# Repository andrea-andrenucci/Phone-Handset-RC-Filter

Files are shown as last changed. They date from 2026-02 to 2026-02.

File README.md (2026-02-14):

# Phone Handset RC Filter
Phones Photo
*I apologise profusely for the inability to make a simple, simmetric photo*
<br></br>

This project is mainly inspired by the works of [Ryan Mobitz](https://www.production-expert.com/production-expert-1/use-an-old-phone-handset-to-produce-a-lo-fi-mic) and [Noisegate](https://noisegate.com.au/how-to-create-a-stereo-microphone-from-an-old-telephone-handset/).

The main contribution of this project is treating the telephone handset as a separate module from the main circuit, which is designed as an independent audio effect stage.

Another major difference is the use of an external power supply. This allows the use of a carbon microphone even without a mixer providing phantom power.  
Thanks to the lower supply voltage (9V instead of the standard 48V phantom power), there is no need for an impedance-matching transformer, significantly reducing manufacturing costs and complexity.

``` Python
The project contains:
    ./imgs/ # All the figures used in the README
    ./schema_and_pcb/ #This contains the main source files
        |
        |-> ./out/ #Files for JLC PCB
        |
        |-> ... # All the kicad files
        |
        |-> ./Case.zip/ #Contains al the .stl for the enclosure
```
More technical info and measurements about the microphone can be found in [MEASUREMENTS](./MEASUREMENTS.md)

## Overview

The circuit is a simple RC-based filter and conditioning stage designed to work with vintage telephone handsets, supporting both the dynamic capsule and the carbon microphone.

The reference in the schematic is an headset from an italian Siemens S62 (aka Bigrigio):

- **Dynamic capsule (≈55 Ω)**
- **Carbon microphone (≈100 kΩ)**

A switch allows selecting the appropriate signal path depending on the capsule type.

The output is provided via a standard **XLR3 panel connector**, making the device compatible with mixers, audio interfaces, and recording systems.

Power is supplied externally through a **9V DC input (center negative)**, the standard de facto for effects.

---

## Electrical Schematic
<center>
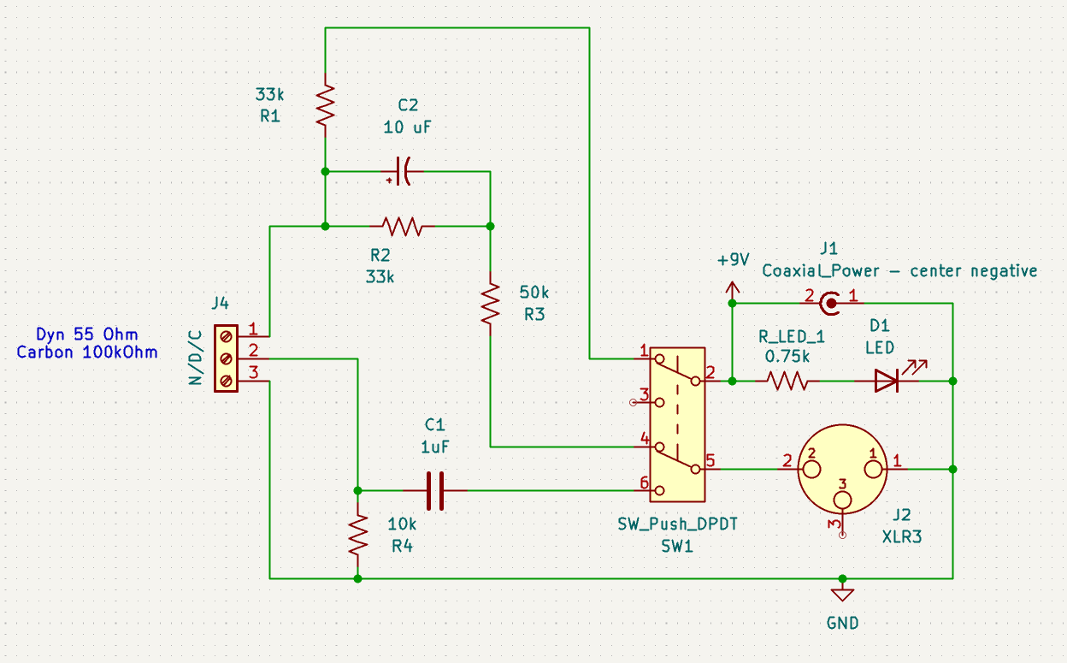
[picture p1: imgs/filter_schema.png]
Filter Schema
    
</center>
<br></br>

Both the schematic and the PCB were designed using **KiCad**.

The circuit can be divided into four main sections:

### 1. Input Section (Handset Connector)
The handset is connected via a 3-pin terminal block:

- Pin 1: Carbon Microphone
- Pin 2: Dynamic Capsule
- Pin 3: Common Ground

<center>
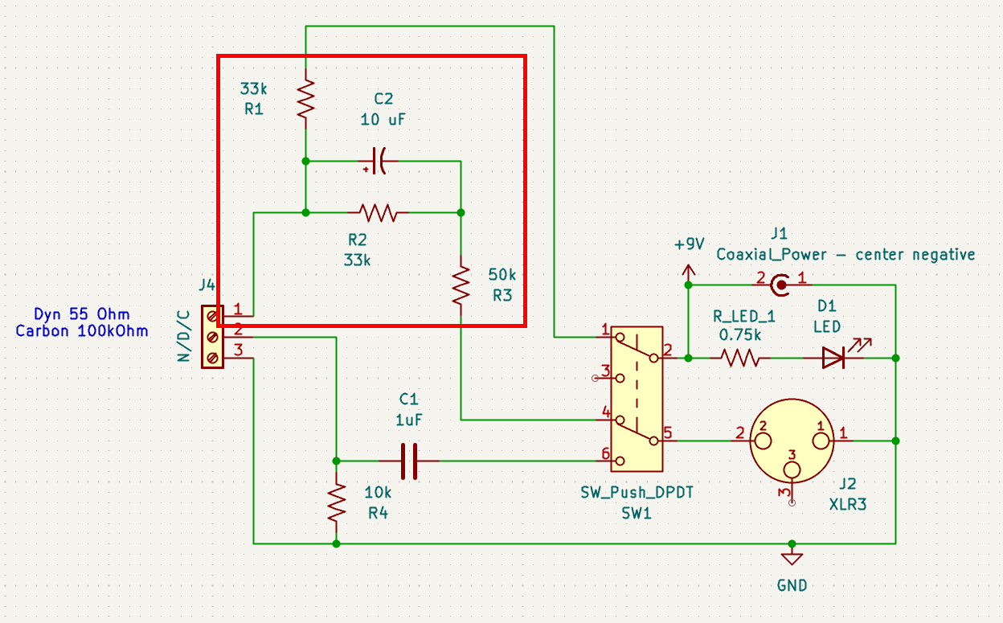
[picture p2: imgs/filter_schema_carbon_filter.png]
Filter Carbon
    
</center>

<br></br>

#### Dynamic Capsule Characteristics

- Very low impedance (~55 Ω)
- Does **not** require bias voltage
- Generates signal directly from diaphragm movement

#### Carbon Microphone Characteristics

- High impedance (~100 kΩ)
- Requires **DC bias current**
- Output is a resistance variation modulating the bias voltage
- Produces strong midrange distortion (classic telephone sound)

Because the two technologies behave completely differently, they require different conditioning paths.

### 2. RC Filter Network
The **R1 (33kΩ)** provides **bias current limiting** for the carbon microphone when in carbon mode. R1:
- Limits current from the 9V supply
- Sets operating point of the carbon capsule
- Prevents excessive noise and overheating

Typical carbon microphones work best with a few milliamps of current.  
33kΩ at 9V provides a safe, low-current bias suitable for vintage elements.

The pair **R2 (33kΩ), C2(10µF)** forms a **high-pass RC filter**.

This network shapes the frequency response, emphasizing the lo-fi telephone character by limiting bandwidth and controlling gain.
The **R3 (50kΩ on the schematic, a 47kΩ was actually used)** resistor acts as a level control.

<center>
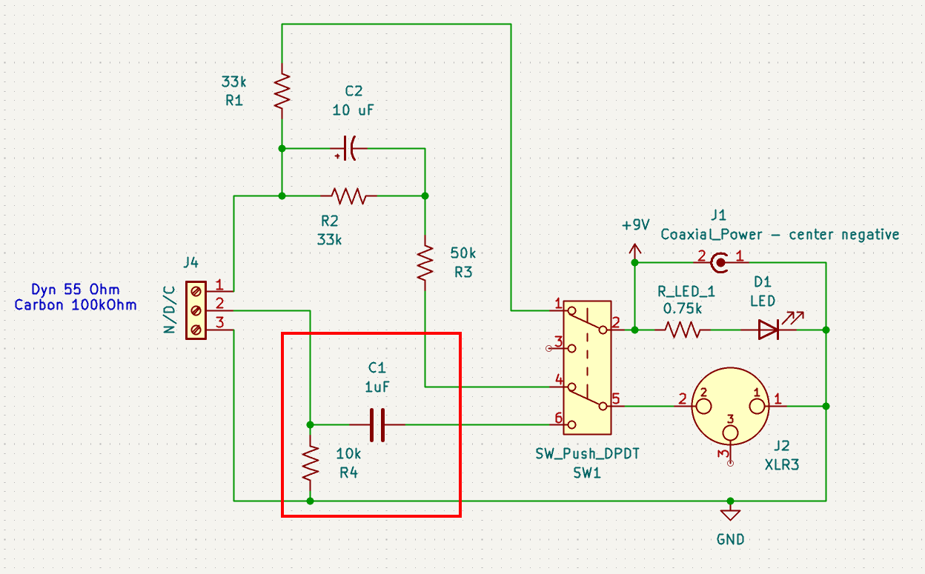
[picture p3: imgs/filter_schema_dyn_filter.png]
Filter Dynamic
    
</center>
<br></br>

**R4 (10kΩ) and C1 (1µF)** work in a similiar fashon, acting as a filter for the dynamic capsule.

This contributes slightly to the “telephone effect”, although the main bandwidth limitation comes from the capsule itself.

### 3. Power and Output Stage

- **9V DC input (center negative)**
- **LED + 750Ω resistor** for power indication
- **XLR3 output connector**

The XLR pinout follows the standard convention:

- Pin 1: Signal -
- Pin 2: Signal +

A **DPDT push switch** allows selecting the correct configuration depending on the capsule type:

- Dynamic mode
- Carbon mode (powered)

This isolates the microphone from the power section when not needed.

<center>
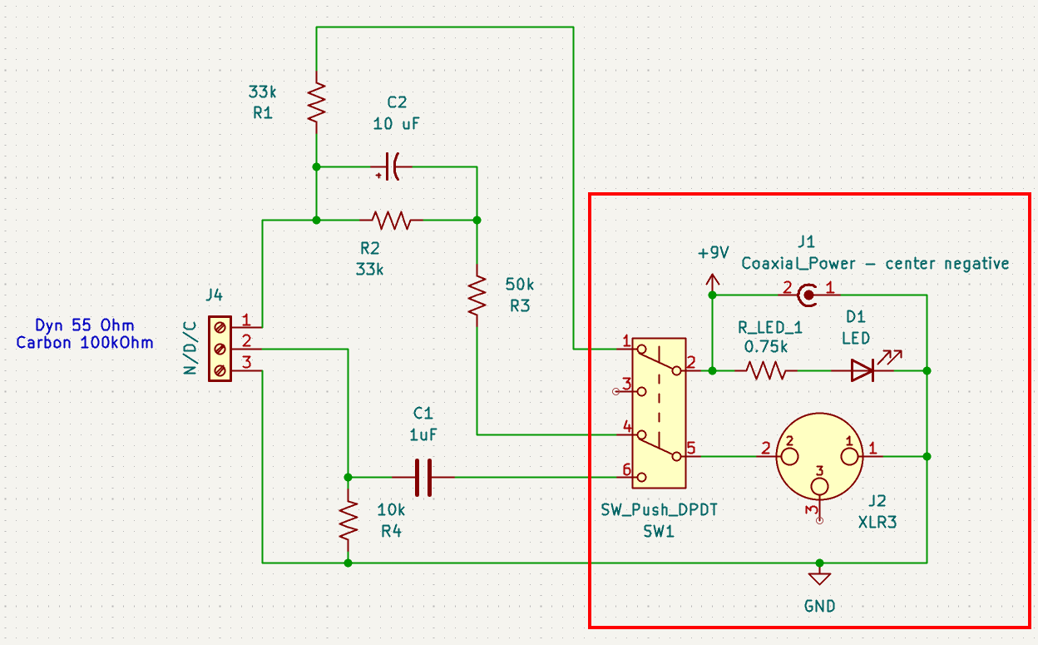
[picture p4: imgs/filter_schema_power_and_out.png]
Filter Power And Output
    
</center>
<br></br>

> Note:  
> This is **not a fully balanced active output**.  
> It is pseudo-balanced/passive and works well for short cable runs.
>
> For professional long runs, an active balanced driver could be added.

---

## PCB

Breadboard

The PCB was designed in KiCad with through-hole components for easy assembly and repair.

Design goals:

- Compact footprint
- Simple routing
- Clear separation between power and signal paths
- Easy integration into a custom enclosure

In order to connect both the DPDT and the XLR i used a **JST** standard 2mm terminal

<center>
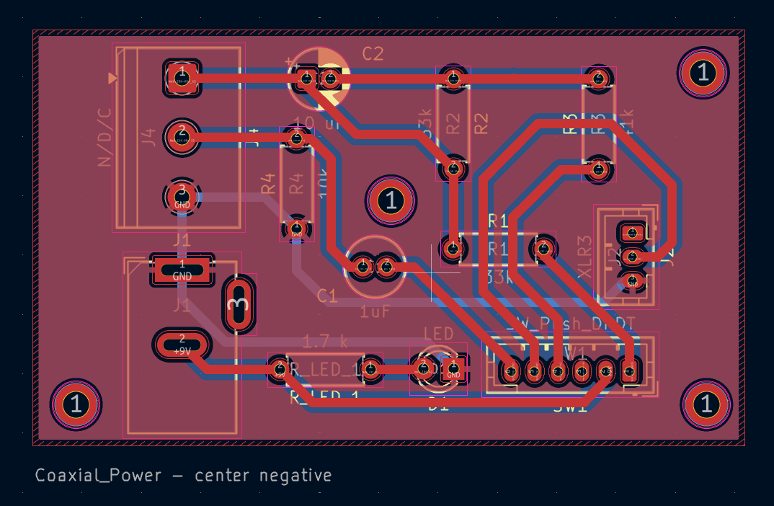
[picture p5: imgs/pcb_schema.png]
PCB Schema
    
</center>

---

## Enclosure

The enclosure was designed in CAD (Onshape) and consists of:

- Base plate
- Main body
- Top plate

The layout ensures mechanical stability and easy access to all connectors.

<center>
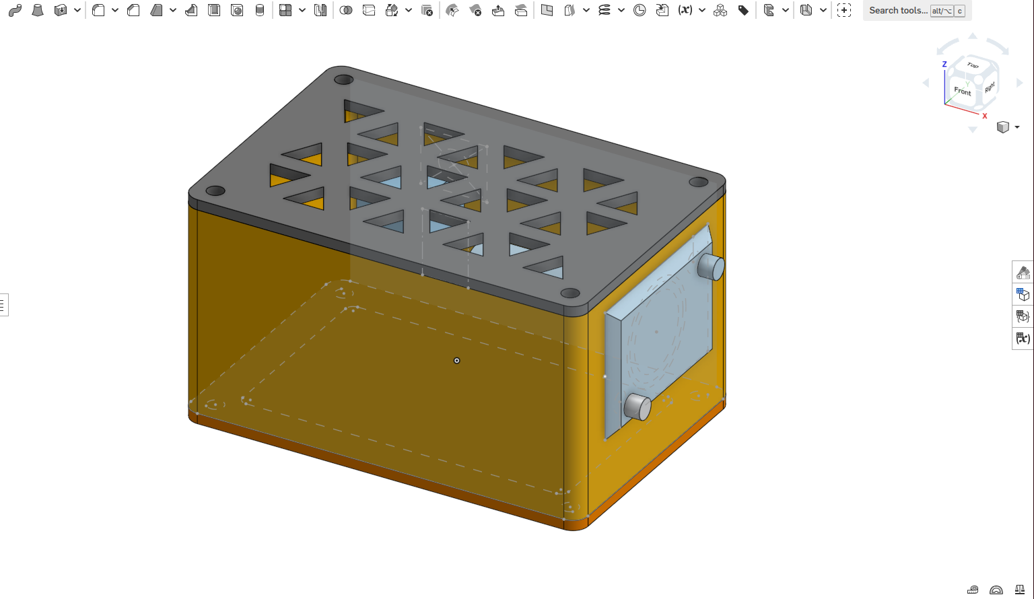
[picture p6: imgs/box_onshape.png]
Box
    
</center>

<center>
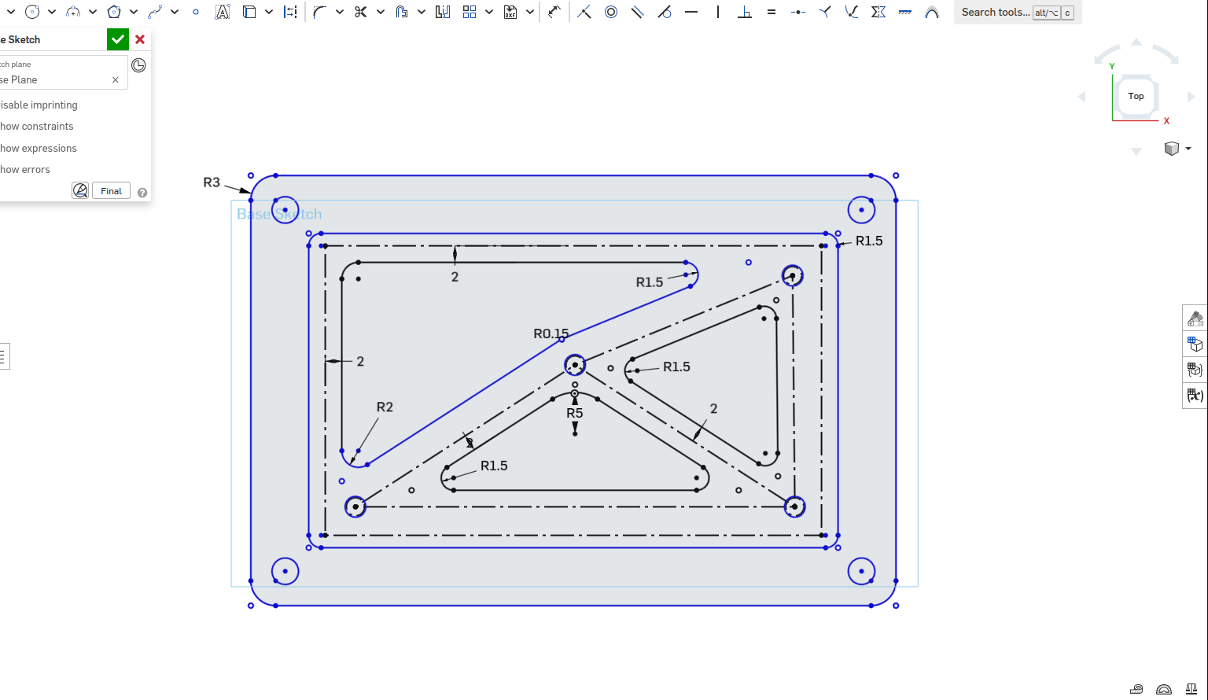
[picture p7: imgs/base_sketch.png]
Box Base
    
</center>

<center>
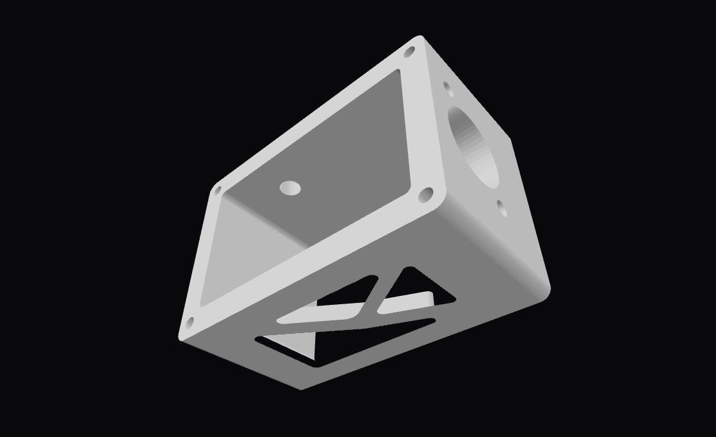
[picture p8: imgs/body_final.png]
Final Body
    
</center>

<center>
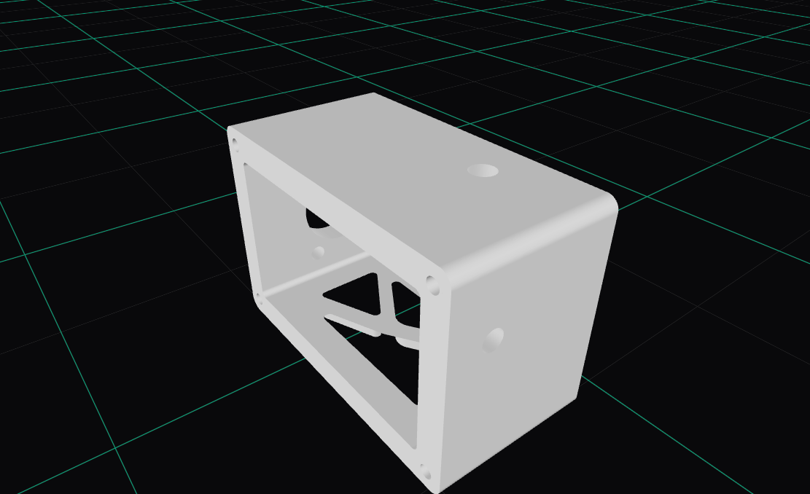
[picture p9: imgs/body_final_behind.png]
Final Body 2
    
</center>

---

## Future Improvements and Considerations

This project started as an experiment and as a way to understand better how simple analog circuits behave in the real world.

It was the first time I designed a complete audio stage from scratch and along the way I definitely made a few mistakes. For example, the value of the **R3 resistor** was tuned empirically after testing with a potentiometer, and only later replaced with the closest fixed value I had available. In hindsight, using a 100kΩ trimmer from the beginning would have made the tuning process much cleaner and more flexible.

I also chose a female XLR panel connector, which is not the standard choice for this kind of device. A male XLR would have been more appropriate, but I worked with what I could source locally at the time.

Despite these imperfections, the device works reliably and captures exactly the grittyness telephone sound.

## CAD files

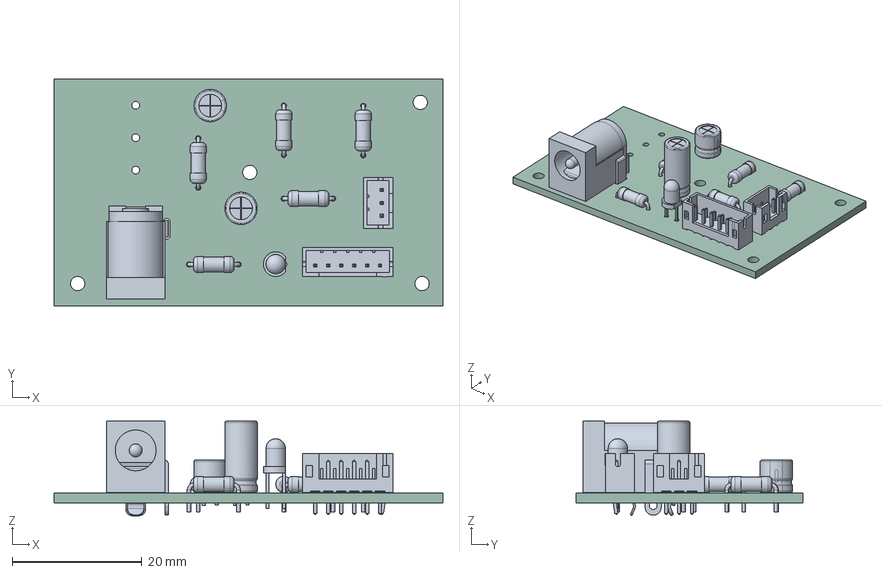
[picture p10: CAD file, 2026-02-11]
schema_and_pcb/phone_mic_jst.step
60.0 x 35.0 x 14.6 mm
LED_D3.0mm
JST_PH_B6B-PH-K_1x06_P2.00mm_Vertical
R_Axial_DIN0207_L6.3mm_D2.5mm_P7.62mm_Horizontal x 5
JST_PH_B3B-PH-K_1x03_P2.00mm_Vertical
BarrelJack_GCT_DCJ200-10-A_Horizontal
CP_Radial_D5.0mm_P2.00mm
C_Radial_D5.0mm_H11.0mm_P2.00mm
phone_mic_jst_PCB

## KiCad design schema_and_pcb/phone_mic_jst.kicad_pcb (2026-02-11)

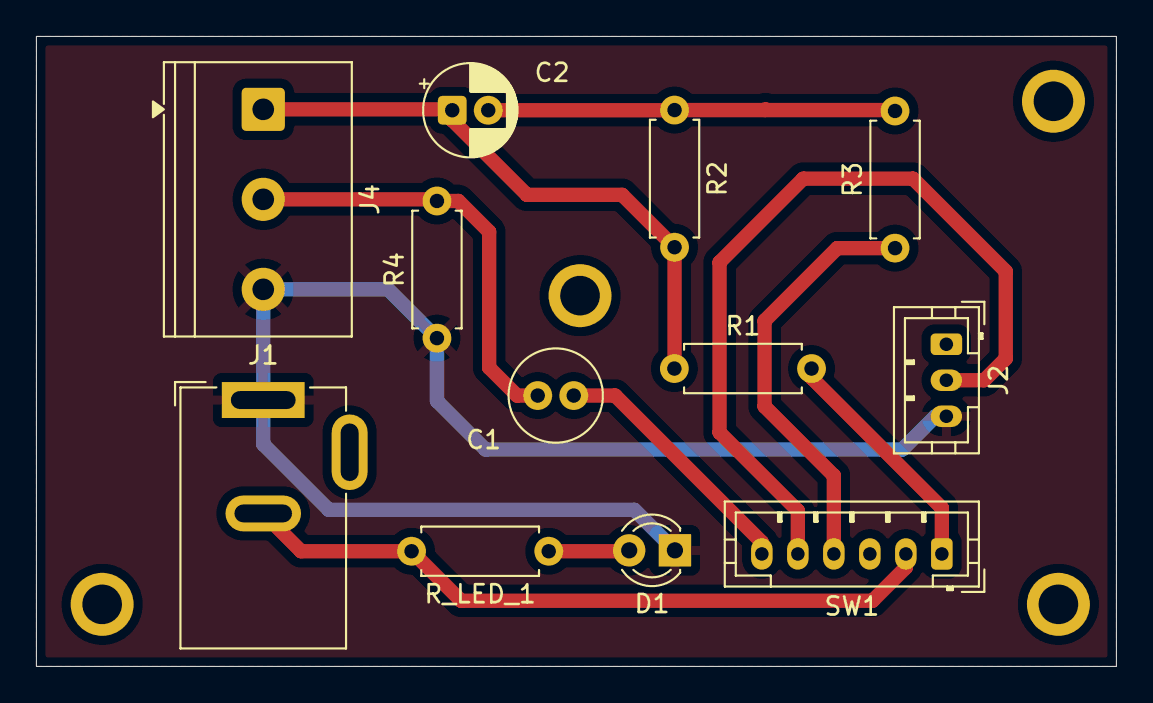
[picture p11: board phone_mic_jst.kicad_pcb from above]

Board: 2 copper layers, 60.0 x 35.0 mm, 12 parts (0 on the bottom side), 10 nets.

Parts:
C1: 1uF; C_Radial_D5.0mm_H11.0mm_P2.00mm
C2: 10 uF; CP_Radial_D5.0mm_P2.00mm
D1: LED; LED_D3.0mm
J1: Coaxial_Power - center negative; BarrelJack_GCT_DCJ200-10-A_Horizontal
J2: XLR3; JST_PH_B3B-PH-K_1x03_P2.00mm_Vertical
J4: N/D/C; TerminalBlock_Philmore_TB133_1x03_P5.00mm_Horizontal
R1, R2: 33k; R_Axial_DIN0207_L6.3mm_D2.5mm_P7.62mm_Horizontal
R3: 41k; R_Axial_DIN0207_L6.3mm_D2.5mm_P7.62mm_Horizontal
R4: 10k; R_Axial_DIN0207_L6.3mm_D2.5mm_P7.62mm_Horizontal
R_LED_1: 1.7 k; R_Axial_DIN0207_L6.3mm_D2.5mm_P7.62mm_Horizontal
SW1: SW_Push_DPDT; JST_PH_B6B-PH-K_1x06_P2.00mm_Vertical

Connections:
+9V: J1.2 (Ext), R_LED_1.2, SW1.2 (B)
GND: D1.1 (K), J1.1 (In), J2.3, J4.3, R4.1
unnamed: C1.2, SW1.6 (C)
unnamed: C2.2, R2.1, R3.2
unnamed: D1.2 (A), R_LED_1.1
unnamed: J2.2, SW1.5 (B)
unnamed: C2.1, J4.1, R1.1, R2.2
unnamed: C1.1, J4.2, R4.2
unnamed: R1.2, SW1.1 (A)
unnamed: R3.1, SW1.4 (A)

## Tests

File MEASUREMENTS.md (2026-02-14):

# Measurements

## Methods

The frequency response of the two microphones was measured using [Room EQ Wizard (REW)](https://www.roomeqwizard.com).

The setup consisted of:
- A Fender Acoustasonic 15 (15 W acoustic guitar amplifier)
- A Behringer Xenyx QX1002USB (mixer with integrated audio interface)

REW generated a sweep signal that was played back through the amplifier.  
Each microphone was connected to the mixer, and REW captured the recorded signal multiple times. The measurements were then averaged and used to generate the frequency response plots.

<center>
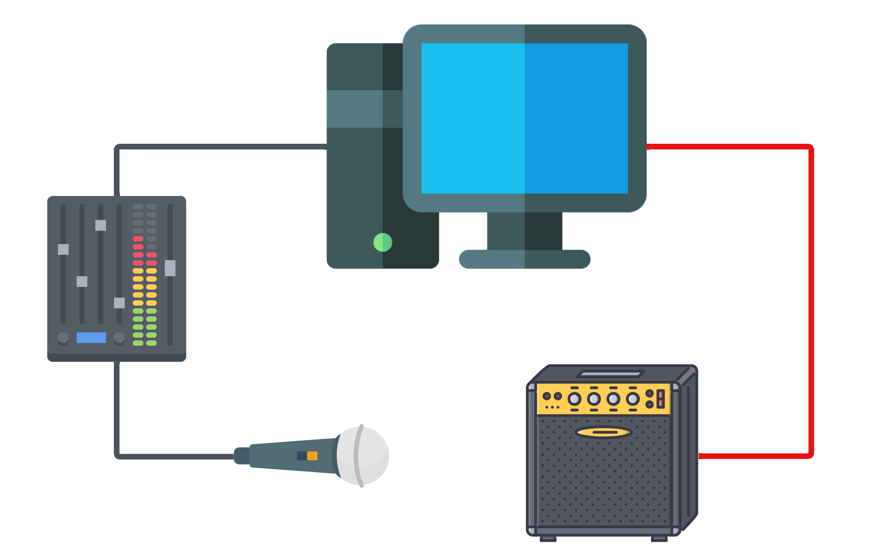
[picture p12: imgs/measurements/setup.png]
setup
    
</center>
<br></br>

A Behringer XM8500 was used for calibration, taking the manufacturer's declared frequency response as a reference.

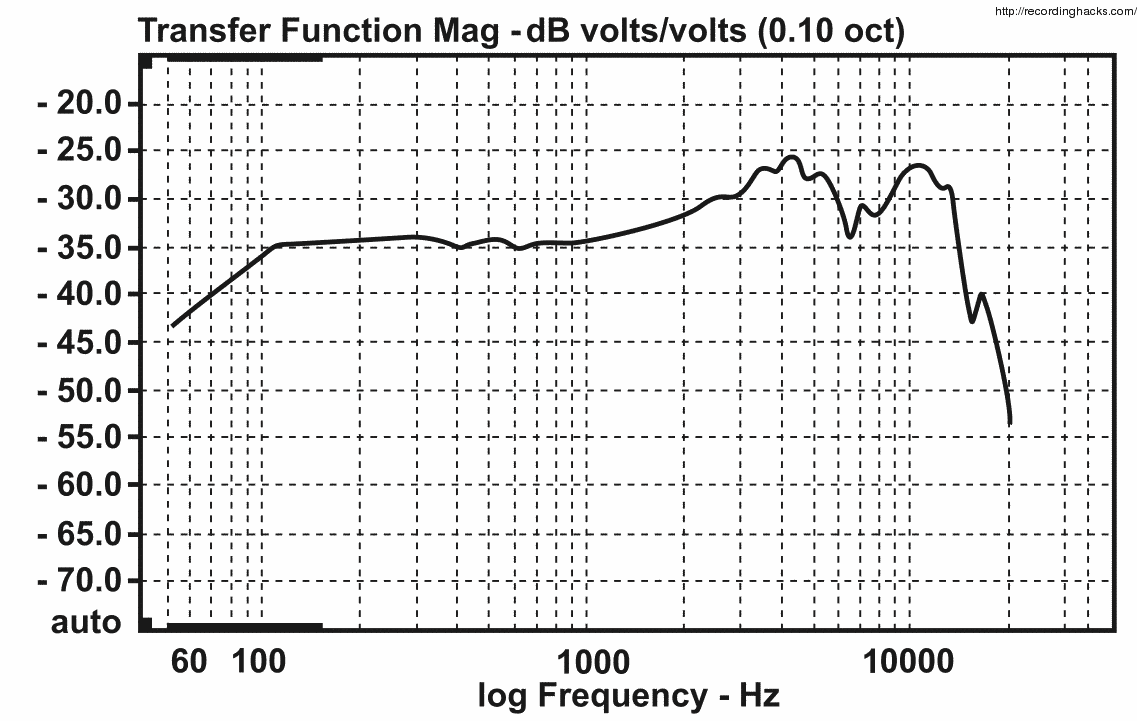
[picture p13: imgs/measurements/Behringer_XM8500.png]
Behringer XM8500 frequency response
  
*Behringer XM8500 – declared frequency response*

The noise profile was taken into account during the measurements.

In the graphs below, the following legend is used:

- <span style="color:#00cccc">Carbon Mic</span>
- <span style="color:#ffccff">Dynamic Mic</span>
- <span style="color:#666666">Behringer XM8500</span> (Reference)

## Results

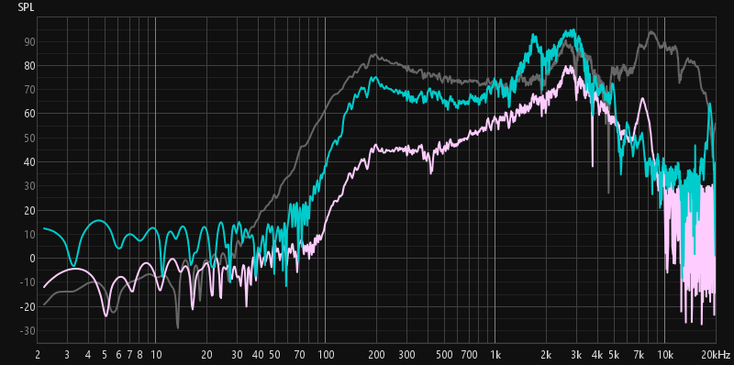
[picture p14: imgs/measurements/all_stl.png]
Comparison of all frequency responses

*Comparison of all frequency responses*

The comparative analysis highlights the "Lo-Fi" nature of the telephone capsules compared to the reference (grey). Both show a steep roll-off below 100 Hz and above 5-7 kHz, concentrating most of the energy within the vocal bandwidth.

---

### Dynamic Mic

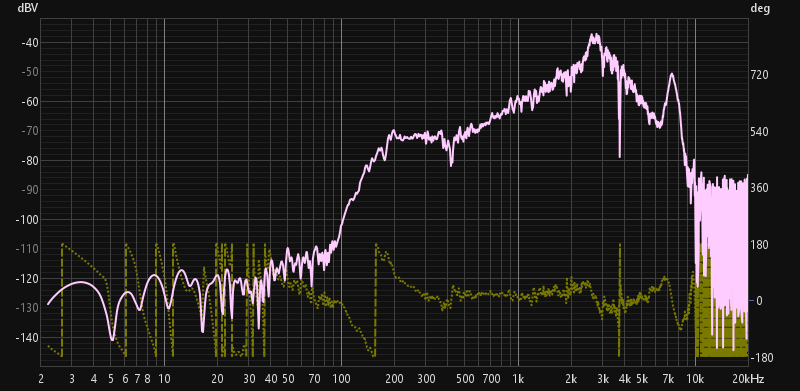
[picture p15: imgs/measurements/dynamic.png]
Dynamic Response

*Dynamic capsule frequency response and phase*

The dynamic capsule (≈55 Ω) exhibits a more controlled response compared to the carbon element:

* **Frequency Response:** It shows a rising emphasis from 200 Hz up to a pronounced peak around **2.5 - 3 kHz**, which is engineered to maximize speech intelligibility.
Beyond 4 kHz, the response decays rapidly, with a final resonance peak near 7-8 kHz before dropping off almost entirely above 10 kHz.
* **Distortion Profile:** * The dominance of the **2nd harmonic** suggests a distortion perceived as "warmer" or less aggressive.
    * The peak in the **2–4 kHz** range directly influences the perception of presence and "bite" in the signal.
    * Overall, it maintains a progressive profile without sudden bursts of high-order harmonics.

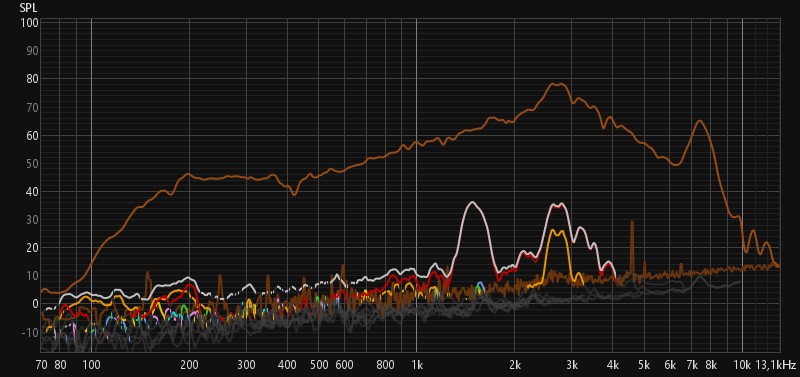
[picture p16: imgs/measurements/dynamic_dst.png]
Dynamic Capsule Distortion Analysis

*Dynamic Capsule Distortion Analysis*
<br></br>

---

### Carbon Mic

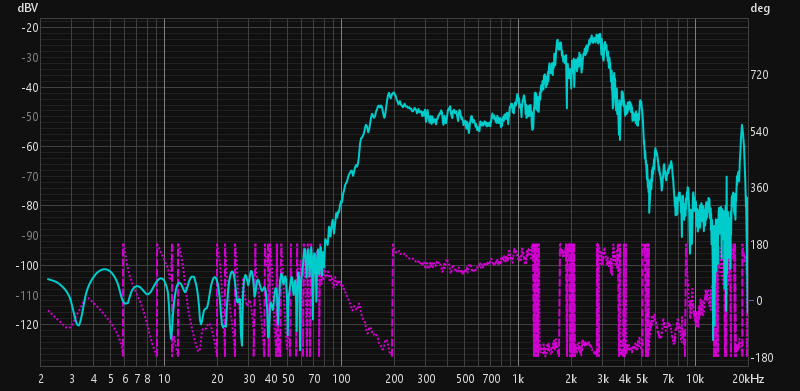
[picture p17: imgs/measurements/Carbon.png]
Carbon Response

*Carbon capsule frequency response and phase*

The carbon capsule (≈100 kΩ) embodies the authentic "vintage telephone" sound due to its non-linear nature:

* **Frequency Response:** It is significantly more irregular than the dynamic capsule. The presence peak is narrower and centered tightly around **3 kHz**, with a much sharper drop-off in both low and high frequencies.
Powered by the 9V bias, the resistance variations of the carbon granules create a very aggressive modulation of the signal, giving the capsule a high gain. 
* **Distortion Profile:**
    * **Higher overall harmonic content:** The THD (Total Harmonic Distortion) is significantly higher than that of the dynamic capsule. The main contribute is given by the **2nd harmonic**. After that, the **3rd and 4th harmonics** 
    * **Consistency:** The higher-order harmonics (5th, 6th, 7th) remain constant and audible, contributing to the characteristic "grit" of carbon microphones.
    * The distortion spectrum is more complex and noisier, making it ideal for creative lo-fi textures.

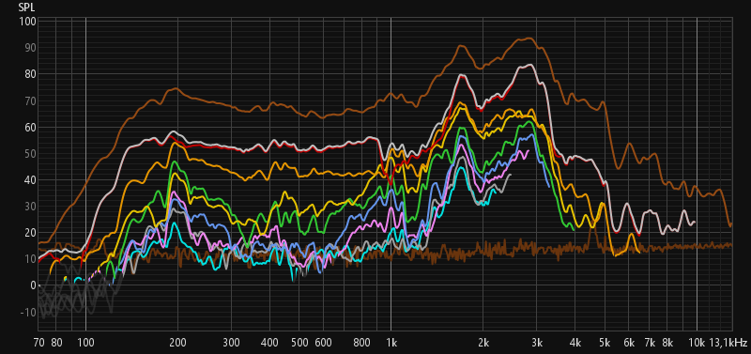
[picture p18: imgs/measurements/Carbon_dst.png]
Carbon Mic Distortion Analysis

*Carbon Mic Distortion Analysis*
<br></br>

### Equalization Advice

//todo

## Threats to Validity

Several factors may have influenced the precision of these measurements. Firstly, the **amplifier's own frequency response** was not subtracted from the final data, meaning the results represent the combined "fingerprint" of the Fender Acoustasonic and the microphones rather than the capsules in isolation. 
**Environmental acoustics** and potential **quantization errors** from the Behringer interface's ADC/DAC conversion could introduce artifacts, especially in the high-frequency range. Additionally, the lack of **rigorous error propagation calculations** and the presence of **EMI/RFI noise** on the unbalanced cables (typical of high-impedance carbon elements) mean that the THD values should be treated as qualitative indicators of "character" rather than absolute laboratory metrics. 
Finally, the calibration against the XM8500 assumes the reference mic perfectly matches its factory spec sheet, which may vary slightly due to manufacturing tolerances.
